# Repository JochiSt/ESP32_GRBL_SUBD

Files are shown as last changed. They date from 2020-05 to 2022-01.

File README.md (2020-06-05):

# ESP32_GRBL_SUBD

ESP32 GRBL adapter to SUB-D25

adapter to use the [ESP32 GRBL port](https://github.com/bdring/Grbl_Esp32) with
usual CNC machines, which are controlled via LPT (SUB-D25)

## PCB
PCBs [version 0.9](https://github.com/JochiSt/ESP32_GRBL_SUBD/releases/tag/v0.9) are available at OSB Park


### TOP side
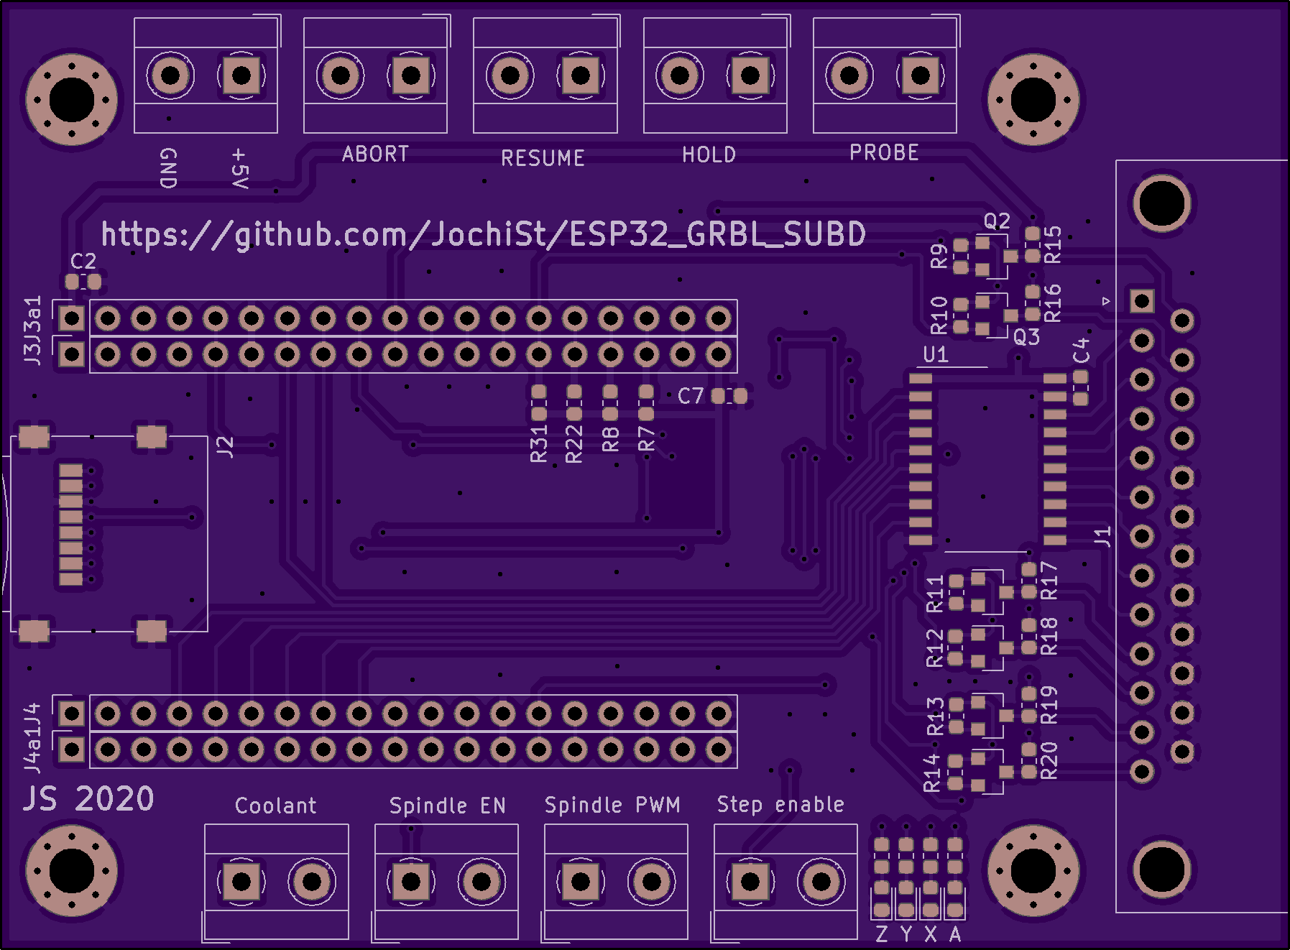
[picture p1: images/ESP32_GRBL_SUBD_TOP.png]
OSHpark Render TOP


### BOT side
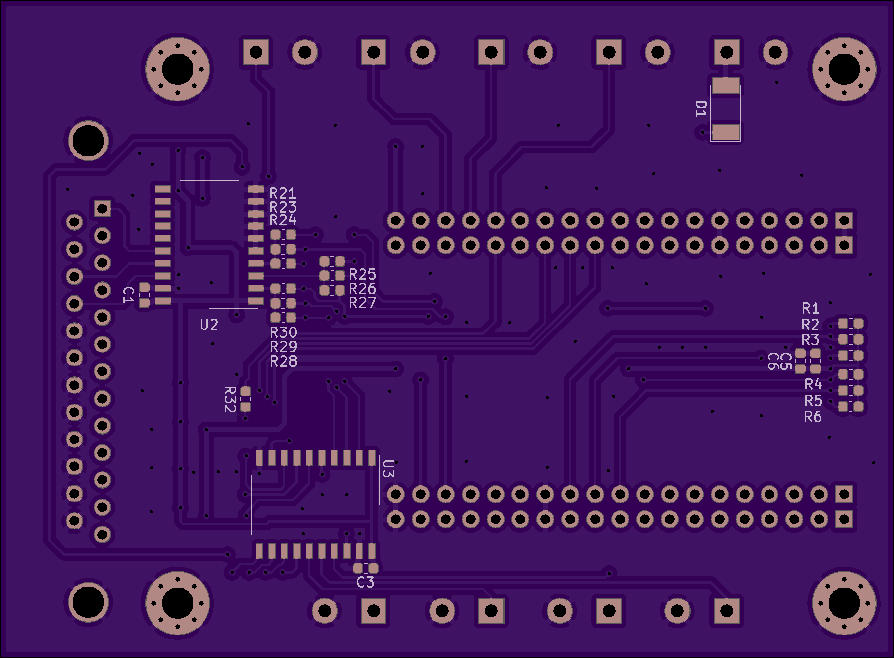
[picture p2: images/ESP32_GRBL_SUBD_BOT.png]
OSHpark Render BOT


### received PCBs
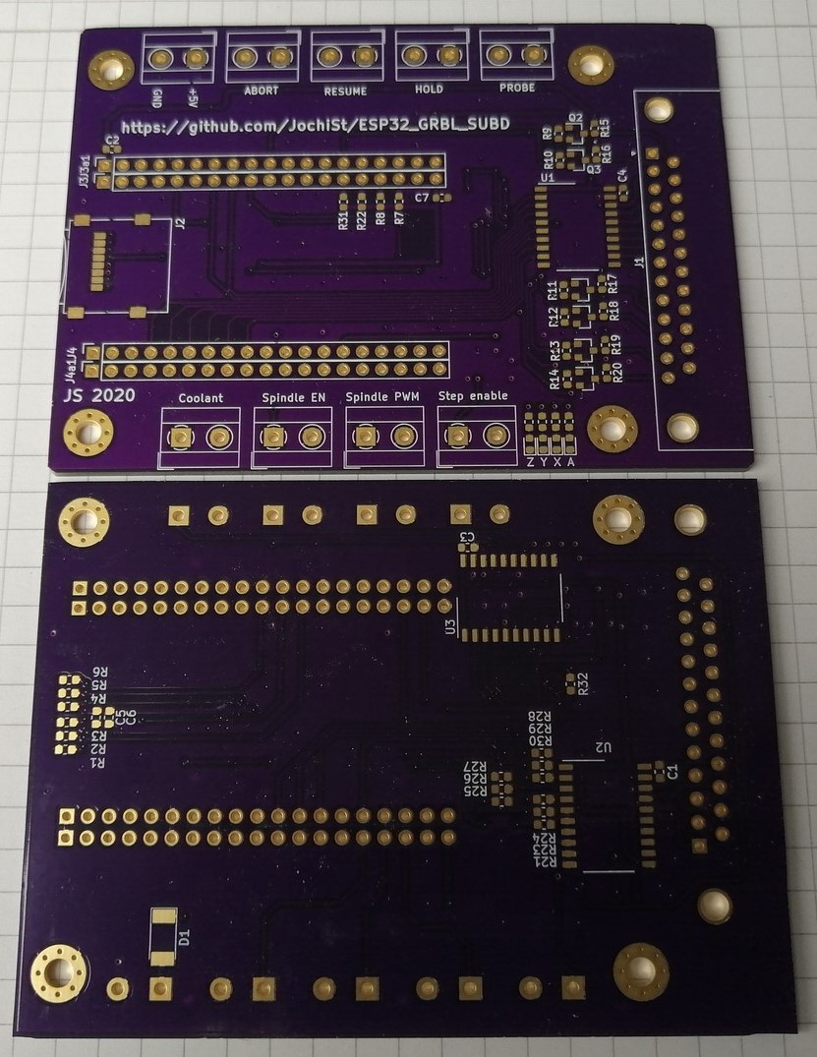
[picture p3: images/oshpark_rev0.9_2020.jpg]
OSHpark received


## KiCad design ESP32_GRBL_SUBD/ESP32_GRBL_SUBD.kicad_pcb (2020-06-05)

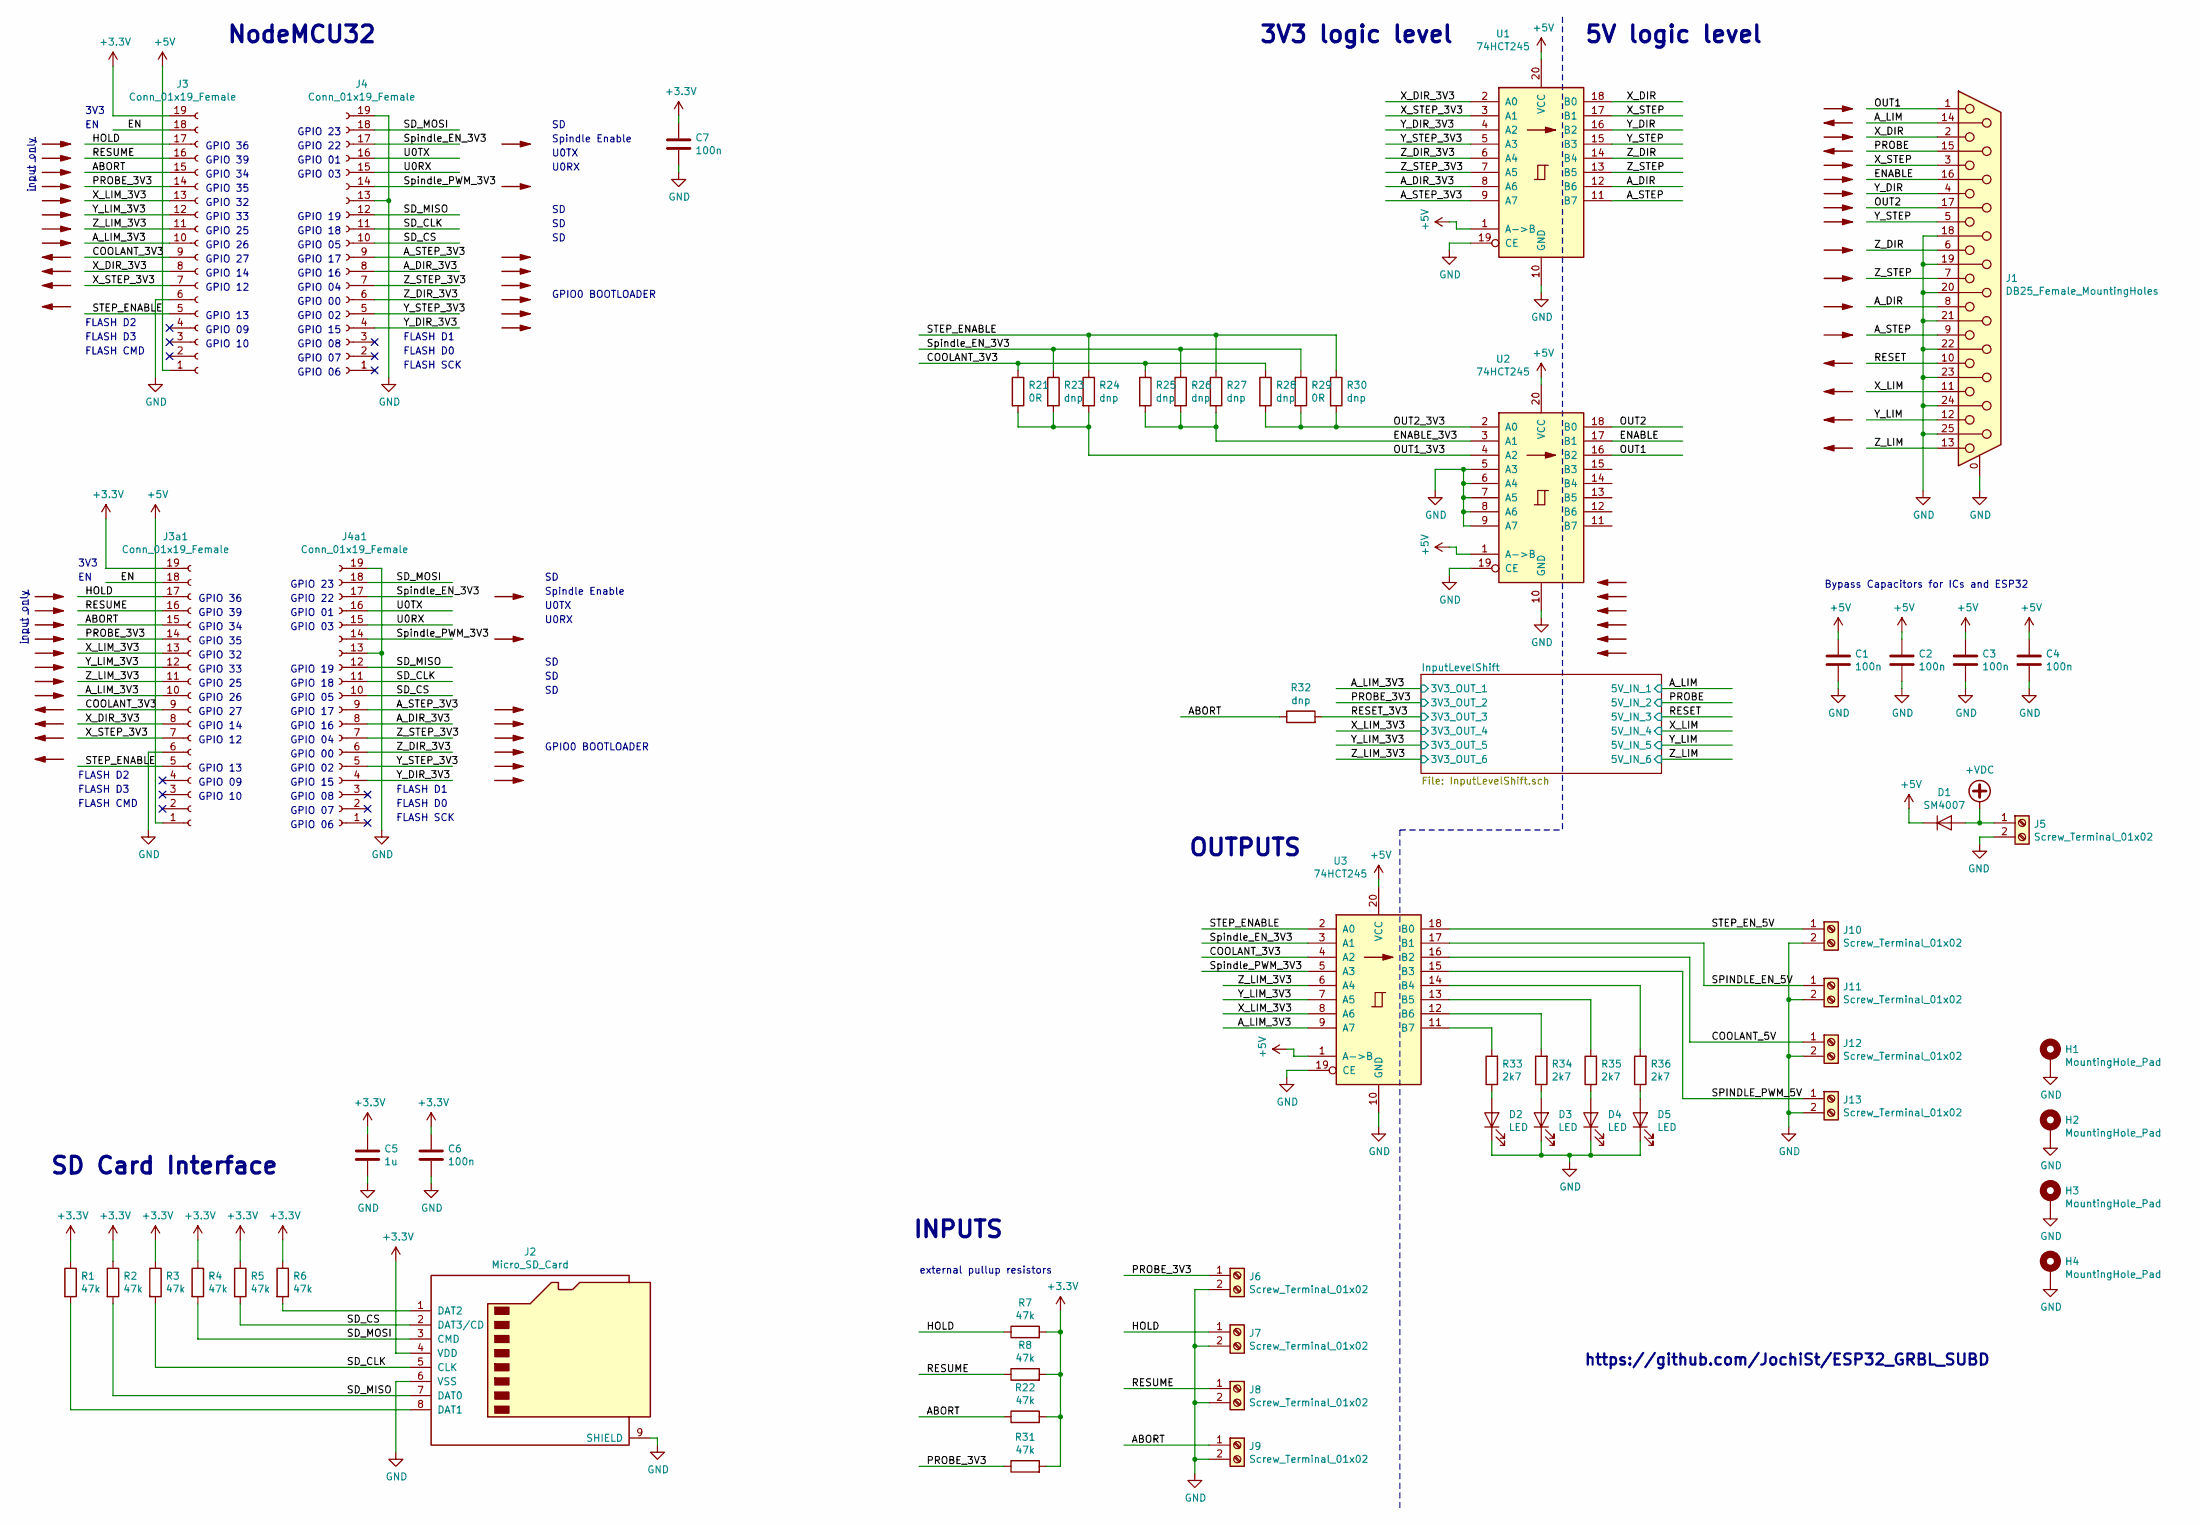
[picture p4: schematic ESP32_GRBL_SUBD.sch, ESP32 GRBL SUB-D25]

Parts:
C1, C2, C3, C4, C6, C7: 100n; C_0603_1608Metric
C5: 1u; C_0603_1608Metric
D1: SM4007; D_MELF
D2, D3, D4, D5: LED; LED_0603_1608Metric
H1, H2, H3, H4: MountingHole_Pad; MountingHole_3.2mm_M3_Pad_Via
J1: DB25_Female_MountingHoles; DSUB-25_Female_Horizontal_P2.77x2.84mm_EdgePinOffset7.70mm_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
J2: Micro_SD_Card; microSD_HC_Wuerth_693072010801
J3, J3a1, J4, J4a1: Conn_01x19_Female; PinSocket_1x19_P2.54mm_Vertical
J5, J6, J7, J8, J9, J10, J11, J12, J13: Screw_Terminal_01x02; TerminalBlock_MetzConnect_Type055_RT01502HDWU_1x02_P5.00mm_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
R1, R2, R3, R4, R5, R6, R7, R8, R22, R31: 47k; R_0603_1608Metric
R21, R29: 0R; R_0603_1608Metric
R23, R24, R25, R26, R27, R28, R30, R32: dnp; R_0603_1608Metric
R33, R34, R35, R36: 2k7; R_0603_1608Metric
U1, U2, U3: 74HCT245; SO-20_12.8x7.5mm_P1.27mm

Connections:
+3V3: C5.1, C6.1, C7.1, J2.4 (VDD), J3.19, J3a1.19, R1.1, R2.1, R3.1, R4.1, R5.1, R6.1, R7.2, R8.2, R22.2, R31.2; also elsewhere on the board
+5V: C1.1, C2.1, C3.1, C4.1, D1.1 (K), J3.1, J3a1.1, U1.1 (A->B), U1.20 (VCC), U2.1 (A->B), U2.20 (VCC), U3.1 (A->B), U3.20 (VCC); also elsewhere on the board
+VDC: D1.2 (A), J5.1
/ABORT: J3.15, J3a1.15, J9.1, R22.1, R32.1
/A_DIR: J1.8, U1.12 (B6)
/A_DIR_3V3: J4.8, J4a1.8, U1.8 (A6)
/A_LIM: J1.14; also elsewhere on the board
/A_LIM_3V3: J3.10, J3a1.10, U3.9 (A7); also elsewhere on the board
/A_STEP: J1.9, U1.11 (B7)
/A_STEP_3V3: J4.9, J4a1.9, U1.9 (A7)
/COOLANT_3V3: J3.9, J3a1.9, R21.1, R25.1, R28.1, U3.4 (A2)
/COOLANT_5V: J12.1, U3.16 (B2)
/EN: J3.18, J3a1.18
/ENABLE: J1.16, U2.17 (B1)
/ENABLE_3V3: R25.2, R26.2, R27.2, U2.3 (A1)
/HOLD: J3.17, J3a1.17, J7.1, R7.1
/OUT1: J1.1, U2.16 (B2)
/OUT1_3V3: R21.2, R23.2, R24.2, U2.4 (A2)
/OUT2: J1.17, U2.18 (B0)
/OUT2_3V3: R28.2, R29.2, R30.2, U2.2 (A0)
/PROBE: J1.15; also elsewhere on the board
/PROBE_3V3: J3.14, J3a1.14, J6.1, R31.1; also elsewhere on the board
/RESET: J1.10; also elsewhere on the board
/RESET_3V3: R32.2; also elsewhere on the board
/RESUME: J3.16, J3a1.16, J8.1, R8.1
/SD_CLK: J2.5 (CLK), J4.11, J4a1.11, R3.2
/SD_CS: J2.2 (DAT3/CD), J4.10, J4a1.10, R5.2
/SD_MISO: J2.7 (DAT0), J4.12, J4a1.12, R2.2
/SD_MOSI: J2.3 (CMD), J4.18, J4a1.18, R4.2
/SPINDLE_EN_5V: J11.1, U3.17 (B1)
/SPINDLE_PWM_5V: J13.1, U3.15 (B3)
/STEP_ENABLE: J3.5, J3a1.5, R24.1, R27.1, R30.1, U3.2 (A0)
/STEP_EN_5V: J10.1, U3.18 (B0)
/Spindle_EN_3V3: J4.17, J4a1.17, R23.1, R26.1, R29.1, U3.3 (A1)
/Spindle_PWM_3V3: J4.14, J4a1.14, U3.5 (A3)
/U0RX: J4.15, J4a1.15
/U0TX: J4.16, J4a1.16
/X_DIR: J1.2, U1.18 (B0)
/X_DIR_3V3: J3.8, J3a1.8, U1.2 (A0)
/X_LIM: J1.11; also elsewhere on the board
/X_LIM_3V3: J3.13, J3a1.13, U3.8 (A6); also elsewhere on the board
/X_STEP: J1.3, U1.17 (B1)
/X_STEP_3V3: J3.7, J3a1.7, U1.3 (A1)
/Y_DIR: J1.4, U1.16 (B2)
/Y_DIR_3V3: J4.4, J4a1.4, U1.4 (A2)
/Y_LIM: J1.12; also elsewhere on the board
/Y_LIM_3V3: J3.12, J3a1.12, U3.7 (A5); also elsewhere on the board
/Y_STEP: J1.5, U1.15 (B3)
/Y_STEP_3V3: J4.5, J4a1.5, U1.5 (A3)
/Z_DIR: J1.6, U1.14 (B4)
/Z_DIR_3V3: J4.6, J4a1.6, U1.6 (A4)
/Z_LIM: J1.13; also elsewhere on the board
/Z_LIM_3V3: J3.11, J3a1.11, U3.6 (A4); also elsewhere on the board
/Z_STEP: J1.7, U1.13 (B5)
/Z_STEP_3V3: J4.7, J4a1.7, U1.7 (A5)
GND: C1.2, C2.2, C3.2, C4.2, C5.2, C6.2, C7.2, D2.1 (K), D3.1 (K), D4.1 (K), D5.1 (K), H1.1, H2.1, H3.1, H4.1, J1.0 (PAD), J1.18, J1.19, J1.20, J1.21, J1.22, J1.23, J1.24, J1.25, J2.6 (VSS), J2.9 (SHIELD), J3.6, J3a1.6, J4.13, J4.19, J4a1.13, J4a1.19, J5.2, J6.2, J7.2, J8.2, J9.2, J10.2, J11.2, J12.2, J13.2, U1.10 (GND), U1.19 (CE), U2.5 (A3), U2.6 (A4), U2.7 (A5), U2.8 (A6), U2.9 (A7), U2.10 (GND), U2.19 (CE), U3.10 (GND), U3.19 (CE)
unnamed: D2.2 (A), R33.1
unnamed: D3.2 (A), R34.1
unnamed: D4.2 (A), R35.1
unnamed: D5.2 (A), R36.1
unnamed: J2.1 (DAT2), R6.2
unnamed: J2.8 (DAT1), R1.2
unnamed: R33.2, U3.11 (B7)
unnamed: R34.2, U3.12 (B6)
unnamed: R35.2, U3.13 (B5)
unnamed: R36.2, U3.14 (B4)

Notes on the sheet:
SD Card Interface
5V logic level
3V3 logic level
Spindle Enable
3V3
FLASH D1
FLASH D0
FLASH SCK
FLASH D2
FLASH D3
FLASH CMD
U0TX
U0RX
GPIO0 BOOTLOADER
NodeMCU32
GPIO 06
GPIO 07
GPIO 08
GPIO 15
GPIO 02
GPIO 00
GPIO 04
GPIO 16
GPIO 17
GPIO 05
GPIO 19
GPIO 18
GPIO 03
GPIO 01
GPIO 22
GPIO 23
GPIO 10
GPIO 09
GPIO 13
GPIO 12
GPIO 14
GPIO 27
GPIO 26
GPIO 25
GPIO 32

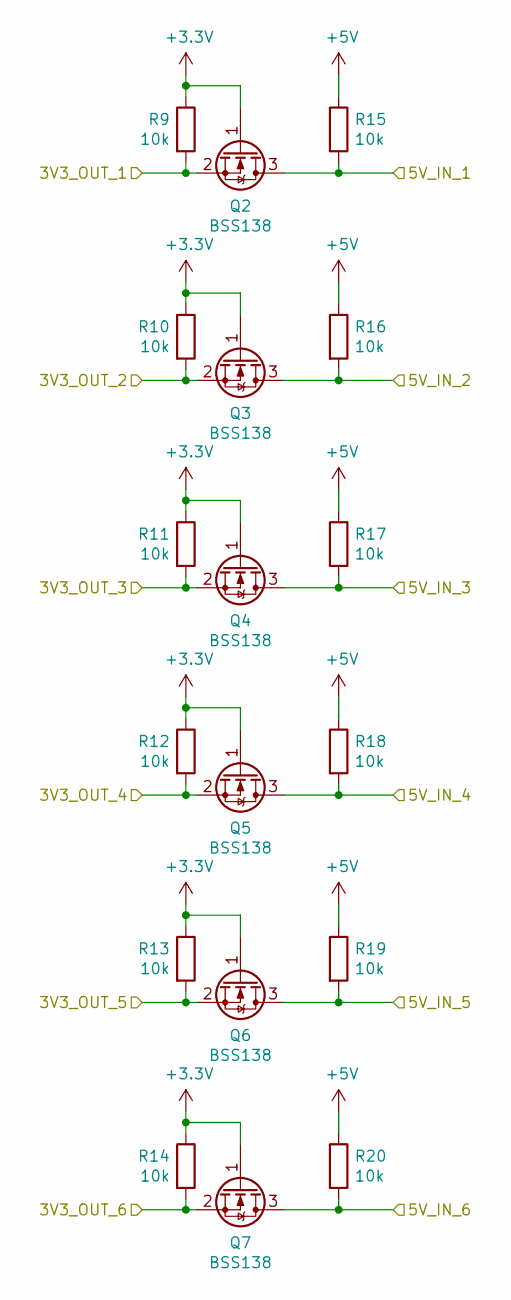
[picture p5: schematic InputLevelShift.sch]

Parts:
Q2, Q3, Q4, Q5, Q6, Q7: BSS138; SOT-23
R9, R10, R11, R12, R13, R14, R15, R16, R17, R18, R19, R20: 10k; R_0603_1608Metric

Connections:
+3V3: Q2.1 (G), Q3.1 (G), Q4.1 (G), Q5.1 (G), Q6.1 (G), Q7.1 (G), R9.1, R10.1, R11.1, R12.1, R13.1, R14.1; also elsewhere on the board
+5V: R15.1, R16.1, R17.1, R18.1, R19.1, R20.1; also elsewhere on the board
/A_LIM: Q2.3 (D), R15.2; also elsewhere on the board
/A_LIM_3V3: Q2.2 (S), R9.2; also elsewhere on the board
/PROBE: Q3.3 (D), R16.2; also elsewhere on the board
/PROBE_3V3: Q3.2 (S), R10.2; also elsewhere on the board
/RESET: Q4.3 (D), R17.2; also elsewhere on the board
/RESET_3V3: Q4.2 (S), R11.2; also elsewhere on the board
/X_LIM: Q5.3 (D), R18.2; also elsewhere on the board
/X_LIM_3V3: Q5.2 (S), R12.2; also elsewhere on the board
/Y_LIM: Q6.3 (D), R19.2; also elsewhere on the board
/Y_LIM_3V3: Q6.2 (S), R13.2; also elsewhere on the board
/Z_LIM: Q7.3 (D), R20.2; also elsewhere on the board
/Z_LIM_3V3: Q7.2 (S), R14.2; also elsewhere on the board

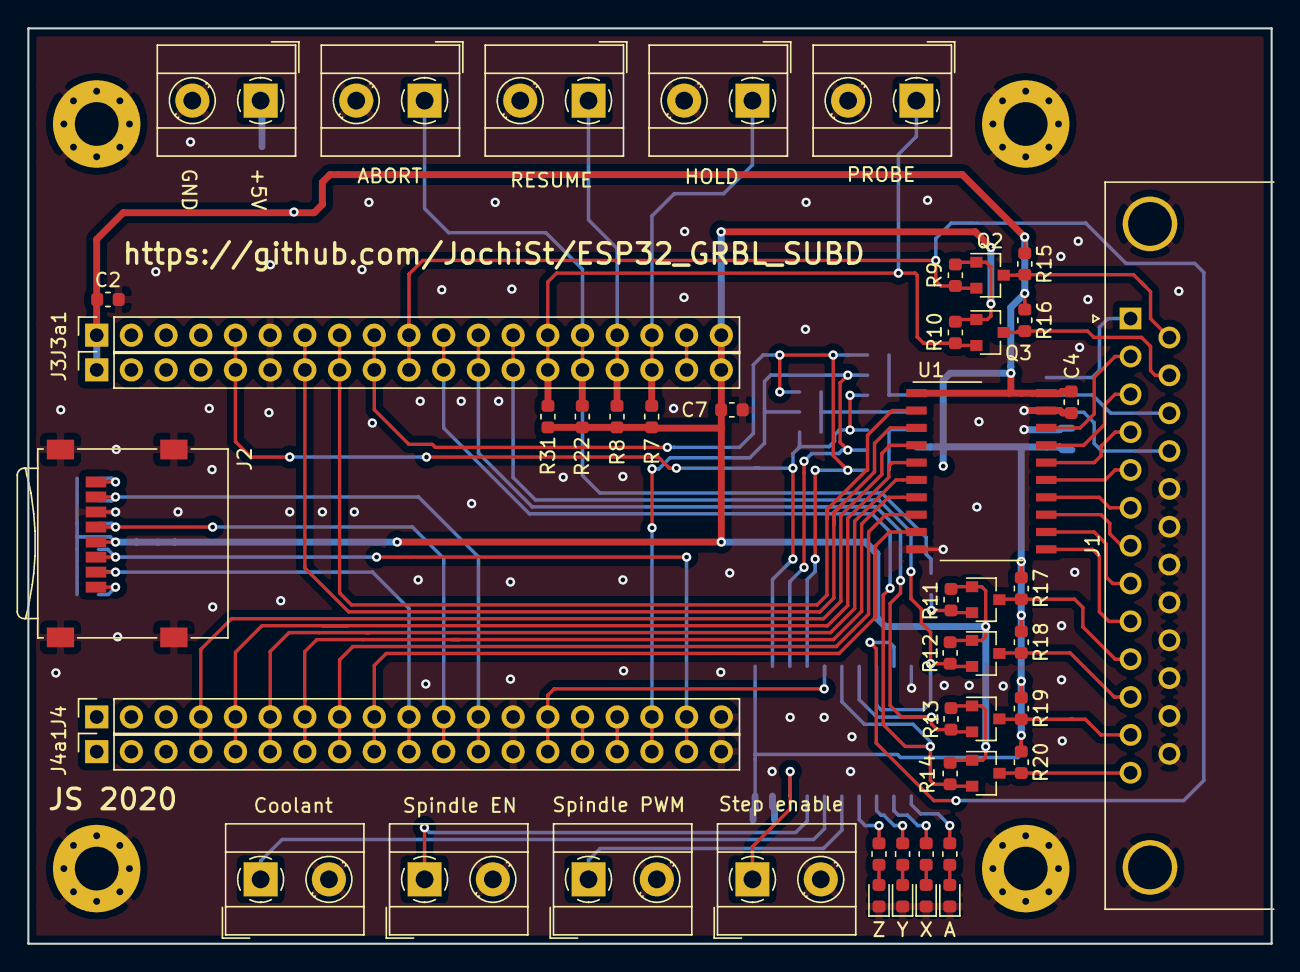
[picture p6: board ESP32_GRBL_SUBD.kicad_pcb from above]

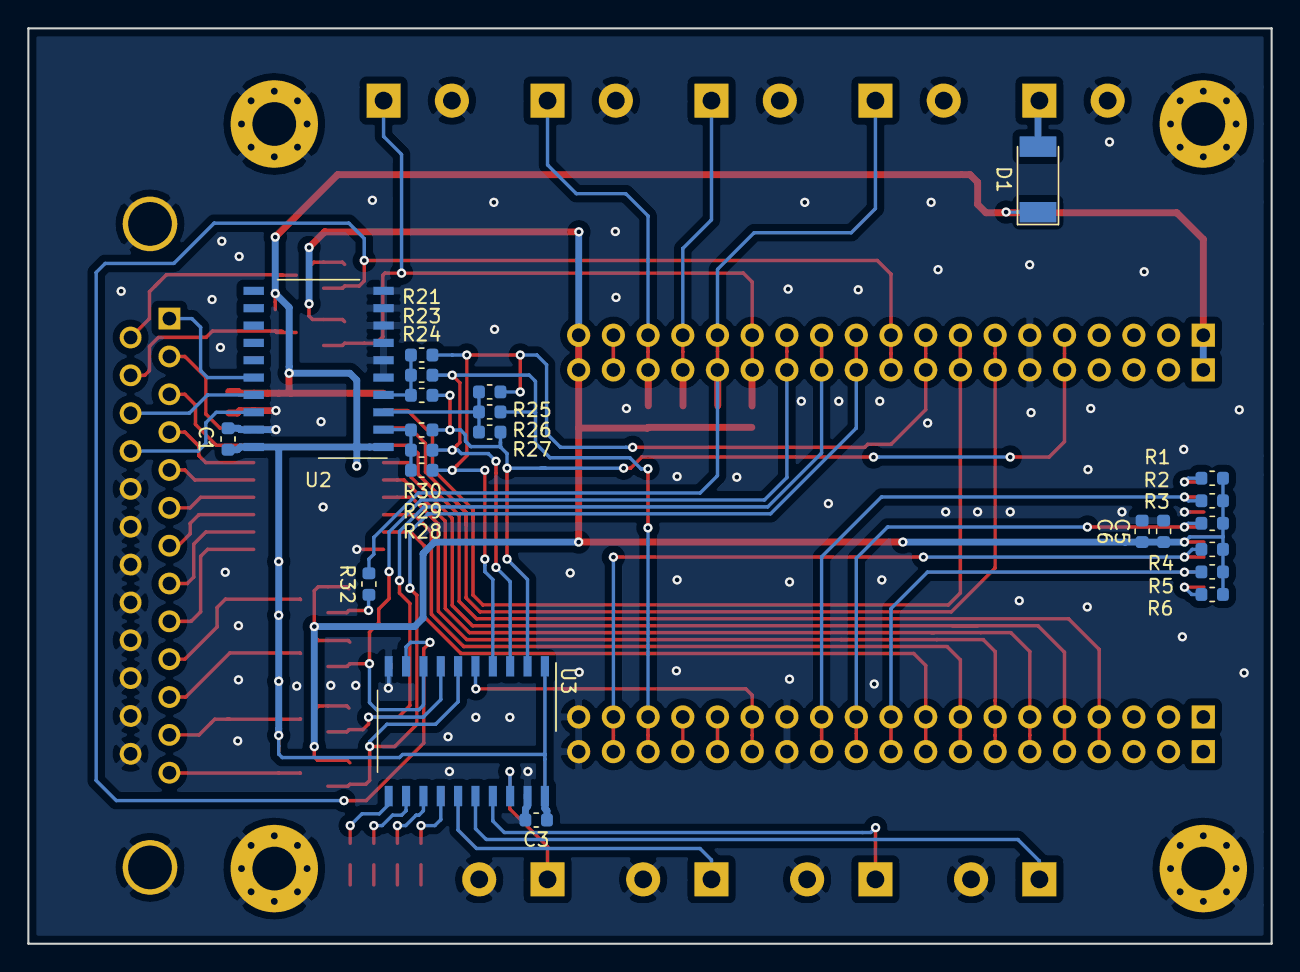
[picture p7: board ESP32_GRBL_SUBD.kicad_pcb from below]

Board: 2 copper layers, 91.0 x 67.0 mm, 76 parts (23 on the bottom side), 66 nets.

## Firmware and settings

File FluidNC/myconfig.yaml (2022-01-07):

name: "ESP32 GRBL SUBD Stepcraft 300"
board: "https://github.com/JochiSt/ESP32_GRBL_SUBD"

stepping:
  engine: RMT
  idle_ms: 250
  dir_delay_us: 1
  pulse_us: 2
  disable_delay_us: 0

axes:
  shared_stepper_disable_pin: gpio.13:low
  
  x:
    steps_per_mm: 133
    max_rate_mm_per_min: 2000
    acceleration_mm_per_sec2: 25
    max_travel_mm: 1000
    homing:
      cycle: 2
      mpos_mm: 10
      positive_direction: false
      
    motor0:
      limit_all_pin: gpio.32:low:pu
      standard_stepper:
        step_pin: gpio.12
        direction_pin: gpio.14
    motor1:
      null_motor:

  y:
    steps_per_mm: 133
    max_rate_mm_per_min: 2000
    acceleration_mm_per_sec2: 25
    max_travel_mm: 1000
    homing:
      cycle: 3
      mpos_mm: 10
      positive_direction: false

    motor0:
      limit_all_pin: gpio.33:low:pu
      standard_stepper:
        direction_pin: gpio.15
        step_pin: gpio.02
    motor1:
      null_motor:

  z:
    steps_per_mm: 133
    max_rate_mm_per_min: 2000
    acceleration_mm_per_sec2: 25
    max_travel_mm: 1000
    homing:
      cycle: 1
      mpos_mm: 10
      positive_direction: true

    motor0:
      limit_all_pin: gpio.25:low:pu
      standard_stepper:
        direction_pin: gpio.00
        step_pin: gpio.04
    motor1:
      null_motor:
      
  a:
    steps_per_mm: 53.400
    max_rate_mm_per_min: 5000.000
    acceleration_mm_per_sec2: 100.000
    max_travel_mm: 960.000
    soft_limits: false
    homing:
      cycle: 2
      positive_direction: false
      mpos_mm: 150.000
      feed_mm_per_min: 100.000
      seek_mm_per_min: 200.000
      settle_ms: 500
      seek_scaler: 1.100
      feed_scaler: 1.100

    motor0:
      limit_neg_pin: NO_PIN
      limit_pos_pin: NO_PIN
      limit_all_pin: gpio.26
      hard_limits: false
      pulloff_mm: 3.000
      standard_stepper:
        step_pin: gpio.17
        direction_pin: gpio.16
    motor1:
      null_motor:
spi:
  miso_pin: gpio.19
  mosi_pin: gpio.23
  sck_pin: gpio.18

sdcard:
  cs_pin: gpio.5
  card_detect_pin: NO_PIN

coolant:
  flood_pin: gpio.27

control:
  safety_door_pin: NO_PIN
  reset_pin: gpio.34
  feed_hold_pin: gpio.36
  cycle_start_pin: gpio.39
  macro0_pin: NO_PIN
  macro1_pin: NO_PIN
  macro2_pin: NO_PIN
  macro3_pin: NO_PIN

probe:
  pin: gpio.35:low

start:
  must_home: true

PWM:
  pwm_hz: 5000
  output_pin: gpio.21
  enable_pin: gpio.22
  direction_pin: NO_PIN
  disable_with_s0: false
  s0_with_disable: true
  spinup_ms: 1000
  spindown_ms: 1000
  tool_num: 0
  speed_map: 0=0% 10000=100%

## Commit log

2020-05-04 added schematics and layout for first version
    [ESP32_GRBL_SUBD.kicad_pcb, ESP32_GRBL_SUBD.sch, InputLevelShift.sch]
2020-05-06 added resistors to map outputs to different pins on SUB-D
    [ESP32_GRBL_SUBD.kicad_pcb, ESP32_GRBL_SUBD.sch]
2020-05-10 added level converter for outputs and some LEDs for limit switches
    [ESP32_GRBL_SUBD.kicad_pcb, ESP32_GRBL_SUBD.sch]
2020-05-10 added decoupling Cs
    [ESP32_GRBL_SUBD.kicad_pcb, ESP32_GRBL_SUBD.sch]
2020-05-10 some cleanup and connections of U0RX / TX and EN to second pin header
    [ESP32_GRBL_SUBD.kicad_pcb, ESP32_GRBL_SUBD.sch]
2020-05-13 added OSHpark rendering of PCBs
2020-06-05 added placement variant of first version
    [ESP32_GRBL_SUBD.kicad_pcb, ESP32_GRBL_SUBD.sch]
2020-06-05 included image of received PCBs in README.md
2022-01-07 started configuration for FluidNC
    started basic configuration for using this adapter PCB with FluidNC
    [myconfig.yaml]
